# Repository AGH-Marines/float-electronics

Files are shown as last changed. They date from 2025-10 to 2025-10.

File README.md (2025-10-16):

# AGH MARINES Measurement Float Electronics

This repository contains the electronic designs for the AGH MARINES autonomous measurement float.  
It includes schematics, PCB layouts, and block diagrams for the main control board, power distribution, and receiver modules.

---

## Project Structure

- **`Float_Main_PCB`** – Main PCB of the float, based on STM32F401, including EEPROM storage and NRF24 RF communication.  
- **`Float_Power_PCB`** – Power PCB featuring a 12V to 3.3V DC-DC step-down (buck) converter, stepper motor driver (DRV8825 StepStick), and filtering capacitors.  
- **`Float_Receiver_PCB`** – Receiver PCB, receiving data via NRF24 RF module and transmitting it to a PC via USB serial.

---

## Tools & Software

- **Altium Designer** – PCB and schematic design software

---

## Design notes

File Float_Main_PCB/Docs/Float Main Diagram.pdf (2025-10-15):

12 V Battery
Pack (8×AA) | Fuse 0.75 A

Step-Down LM2596
12V -> 3.3V

DRV8825
Stepper Driver

17HD40005
NEMA17 Stepper

STM32F401

M93C66
EEPROM

nRF24L01+
Transceiver

Bar30
Pressure Sensor

Vertical Float

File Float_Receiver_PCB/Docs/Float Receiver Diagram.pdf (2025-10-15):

USB-C
USB 2.0

USBLC6-2SC6
ESD Protection

XC6206
Voltage regulator | STM32F401CCU6

nRF24L01+
Transceiver

Vertical Float Receiver

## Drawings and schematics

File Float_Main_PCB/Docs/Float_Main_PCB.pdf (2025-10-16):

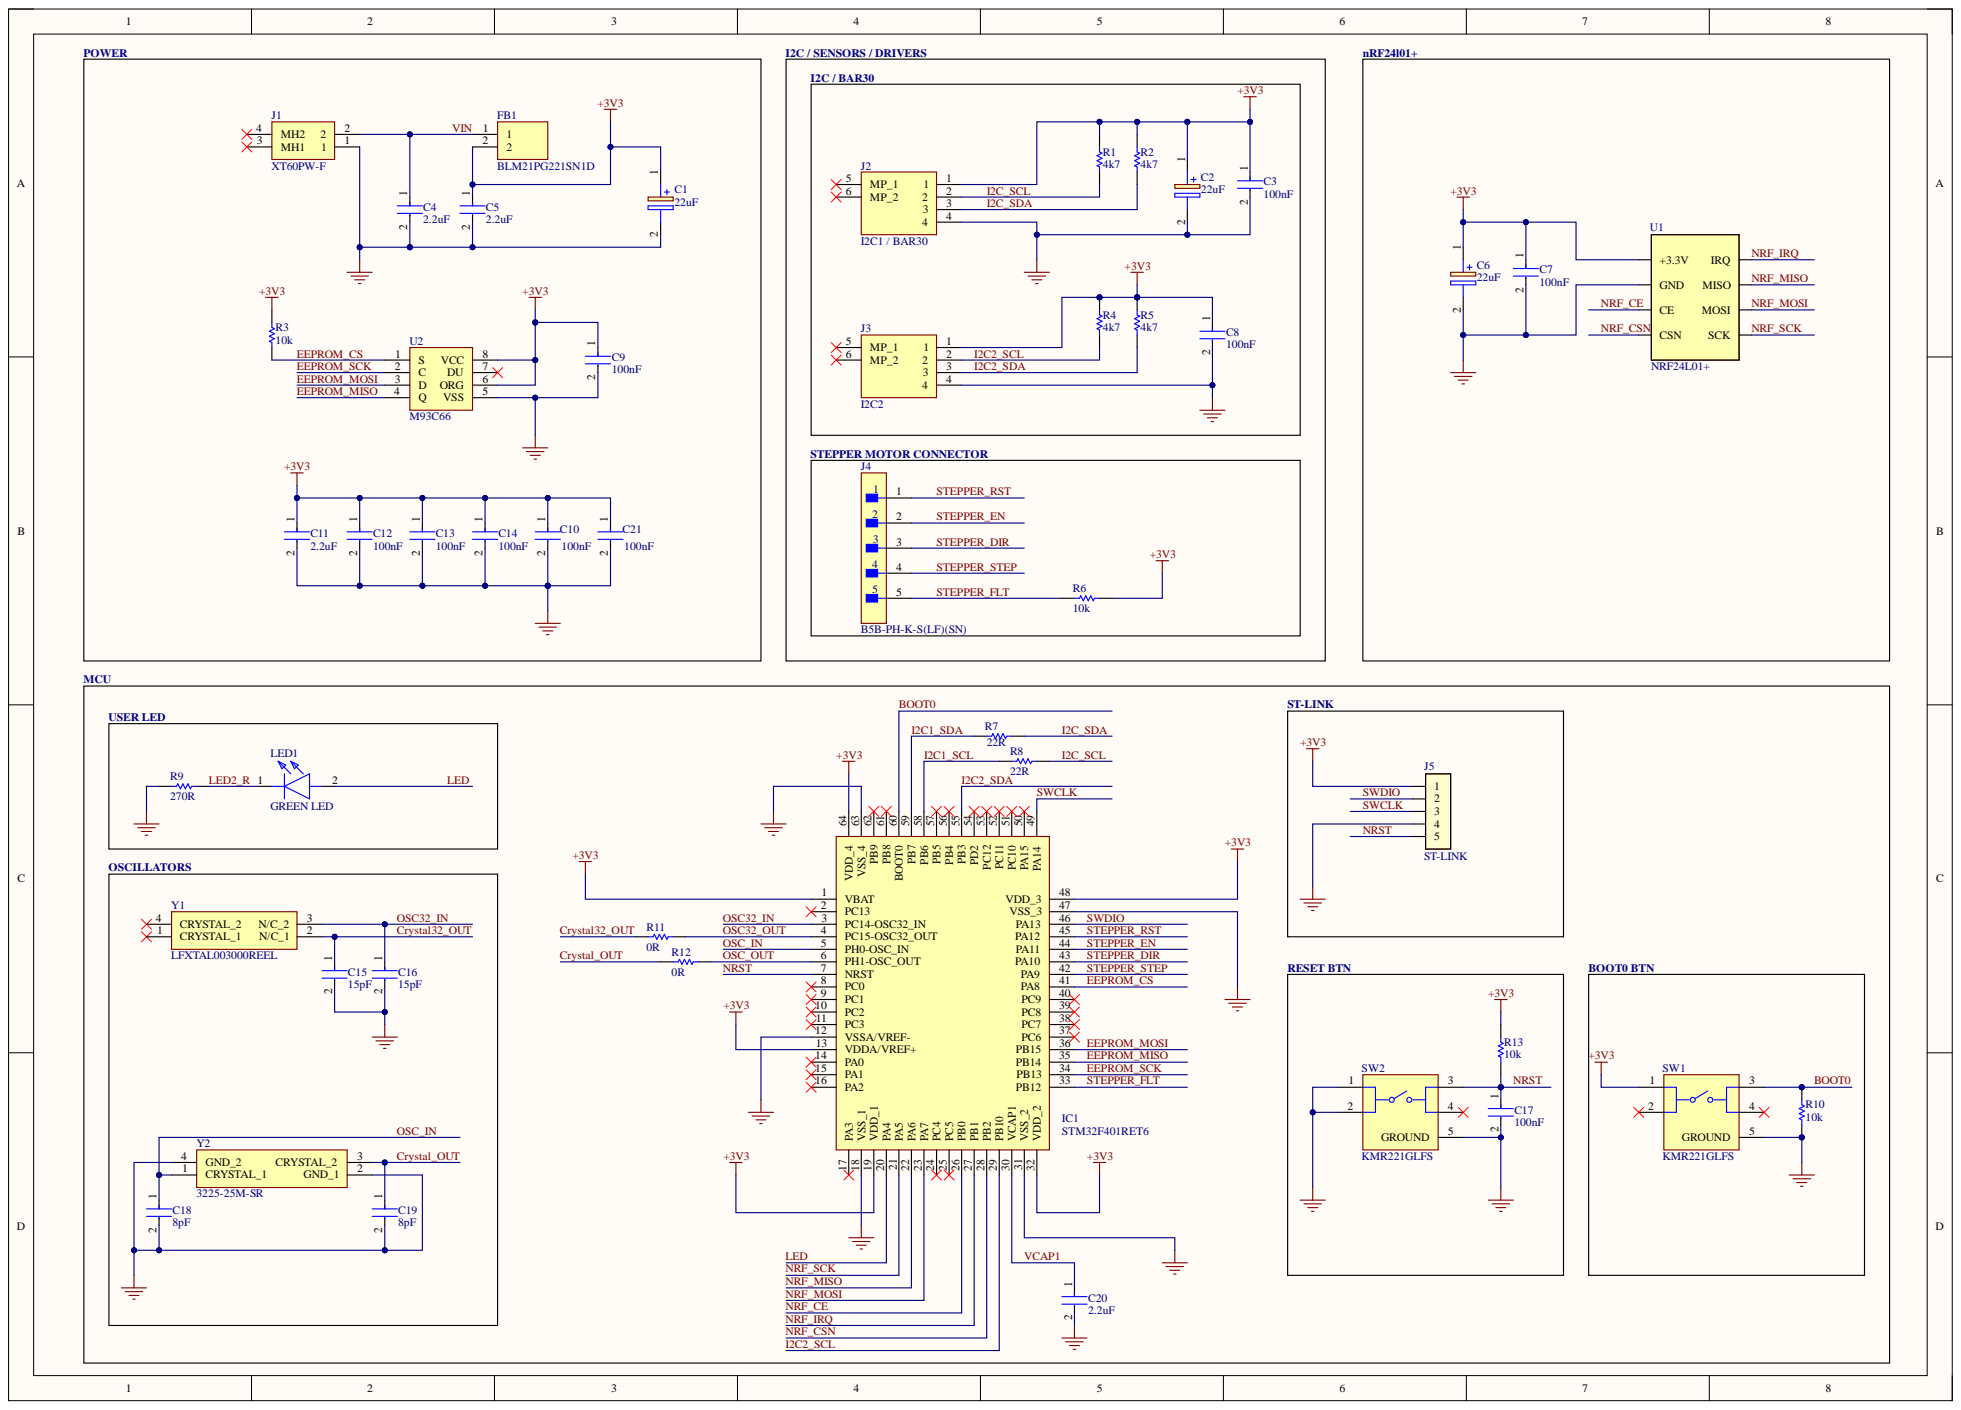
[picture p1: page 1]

I2C1_SCL | R8 I2C_SCL

I2C2_SDA

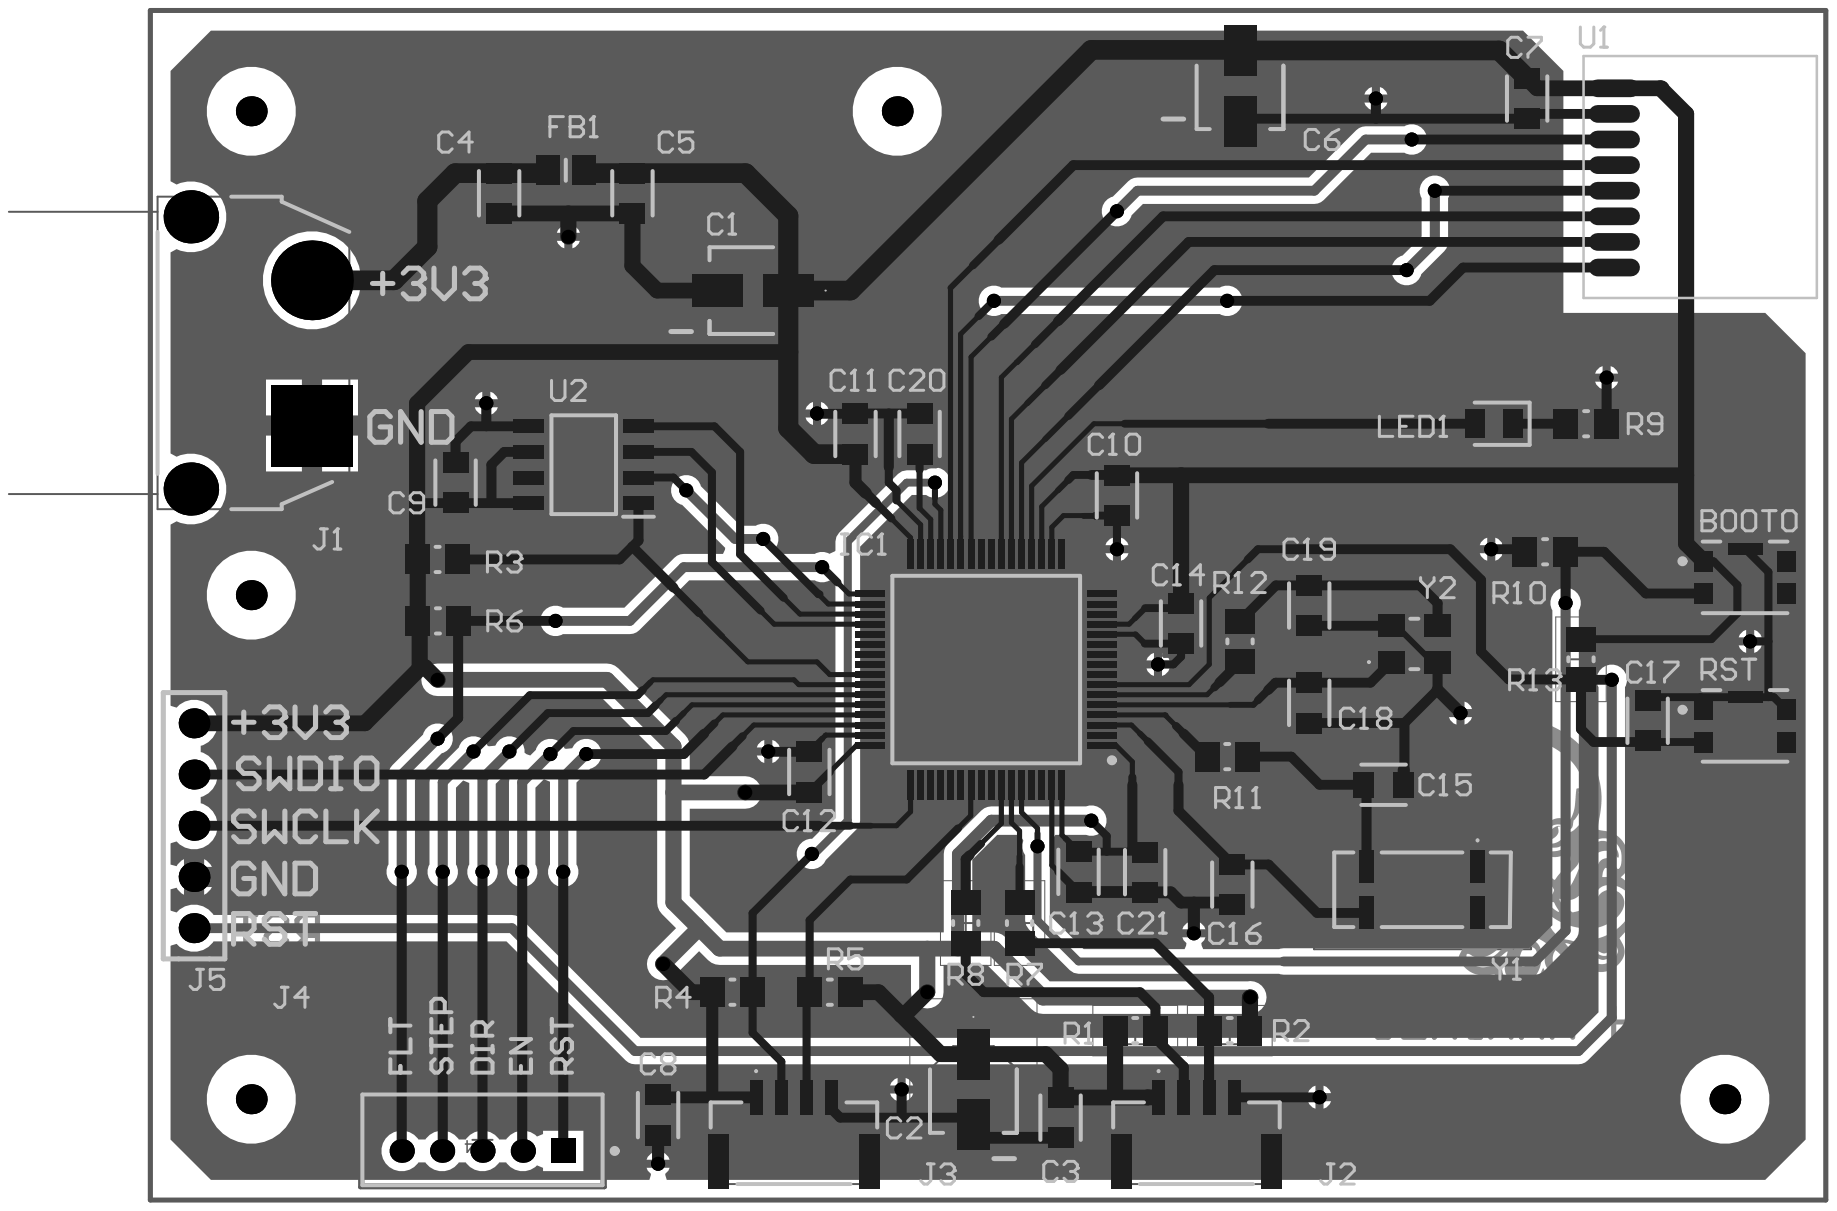
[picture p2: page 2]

Comment | Description | Designator | Footprint | LibRef | Quantity
22uF | Capacitor Polarised | C1, C2, C6 | EEE1AA220WR | EEE1CA100SR | 3
100nF | | C3, C7, C8, C9, C10, C12, C13, C14, C17, C21 | FP-0805-L_2_01_0_2-W_1_25-MFG | CMP-1036-04738-3 | 10
2.2uF | | C4, C5, C11, C20 | FP-0805-L_2_01_0_2-W_1_25-MFG | CMP-1036-04738-3 | 4
15pF | | C15, C16 | FP-0805-L_2_01_0_2-W_1_25-MFG | CMP-1036-04738-3 | 2
8pF | | C18, C19 | FP-0805-L_2_01_0_2-W_1_25-MFG | CMP-1036-04738-3 | 2
BLM21PG221SN1D | FerriteBead | FB1 | BEADC2012X105N | BLM21PG221SN1D | 1
STM32F401RET6 | IntegratedCircuit | IC1 | QFP50P1200X1200X1 60-64N | STM32F401RET6 | 1
XT60PW-F | Connector | J1 | XT60PWF | XT60PW-F | 1
I2C1/ BAR30 | Connector | J2 | SM04BGHSTBLFSN | SM04B-GHS-TB__LF__SN_ | 1
I2C2 | Connector | J3 | SM04BGHSTBLFSN | SM04B-GHS-TB__LF__SN_ | 1
B5B-PH-K-S(LF)(SN) | CONNHEADERVERT 5POS2MM | J4 | FP-B5B-PH-K-S_LF_SN-MFG | CMP-2000-05908-2 | 1
ST-LINK | | J5 | goldpin5 | CMP-008-000005-1 | 1
GREENLED | LED | LED1 | LEDC2012X80N | HSMG-C170 | 1
4k7 | | R1, R2, R4, R5 | RESC2013X60X35ML1 0T20 | CMP-2100-03671-1 | 4
10k | | R3, R6, R10, R13 | RESC2013X60X35ML1 0T20 | CMP-2100-03671-1 | 4
22R | | R7, R8 | RESC2013X60X35ML1 0T20 | CMP-2100-03671-1 | 2
270R | | R9 | RESC2013X60X35ML1 0T20 | CMP-2100-03671-1 | 1
0R | | R11, R12 | RESC2013X60X35ML1 0T20 | CMP-2100-03671-1 | 2
KMR221GLFS | SWITCHTACTILESPST-NO0.05A32V | SW1, SW2 | FP-KMR221GLFS-MFGCMP-10040-000018-1 | | 2
NRF24L01+SMD | | U1 | PCBComponent_1 | NRF24L01+SMD | 1
M93C66 | IntegratedCircuit | U2 | SOIC127P600X175-8NM93C66-WMN6TP | | 1
LFXTAL003000REEL | Crystal or Oscillator | Y1 | LFXTAL003000REEL | LFXTAL003000REEL | 1
3225-25M-SR | Crystal or Oscillator | Y2 | 322525MSR | 3225-25M-SR | 1

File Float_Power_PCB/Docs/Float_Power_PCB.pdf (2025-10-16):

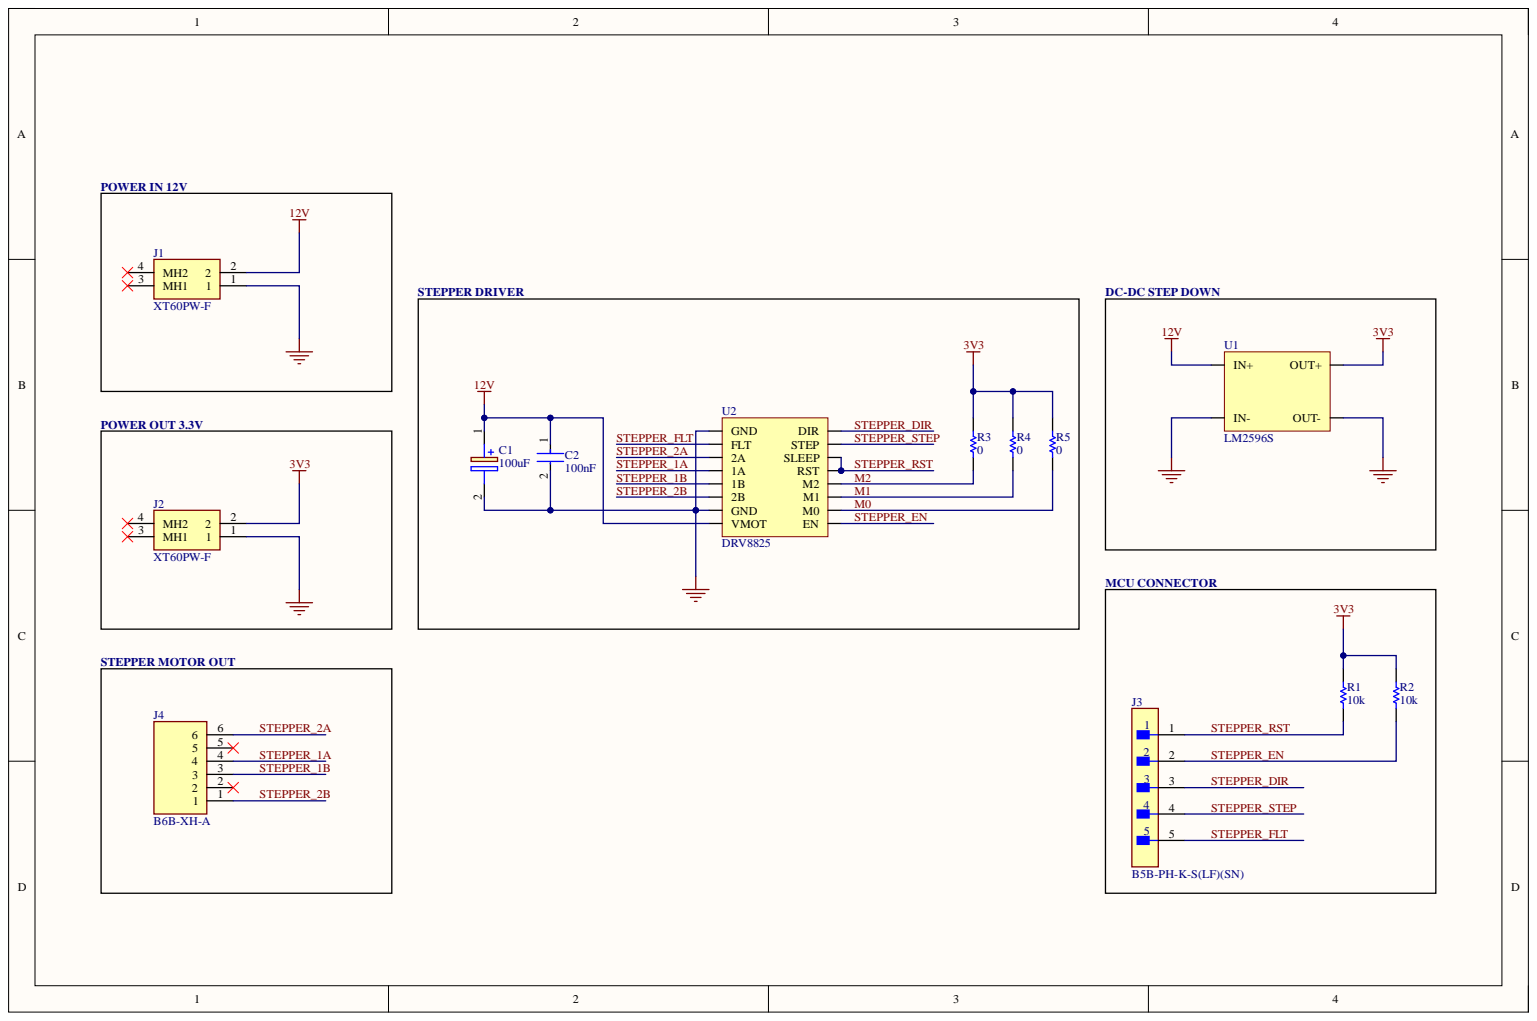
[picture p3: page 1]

DC-DC STEP DOWN

STEPPER_RST
M2

2 | 2 | STEPPER_EN

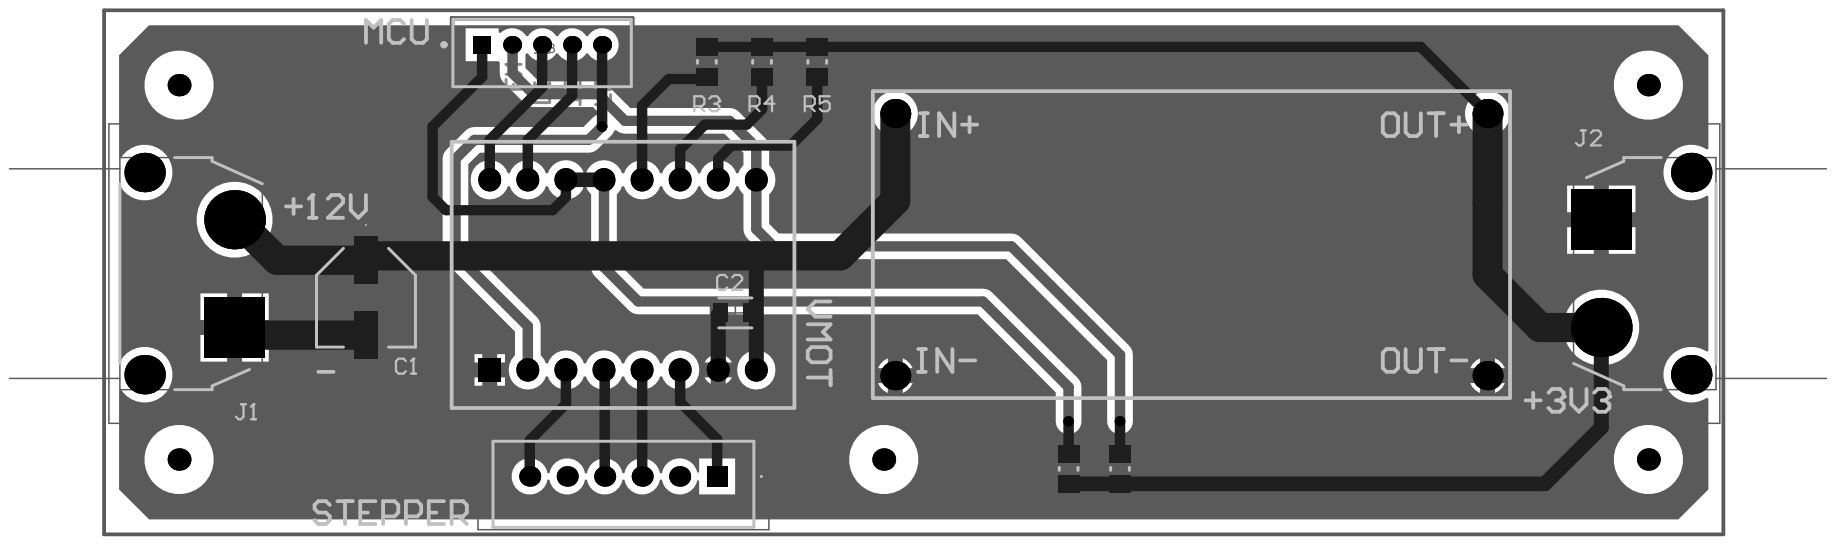
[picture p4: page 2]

Comment | Description | Designator | Footprint | LibRef | Quantity
100uF | Capacitor Polarised | C1 | EEHZA1E101XP | EEHZA1E101XP | 1
100nF | | C2 | FP-0805-L_2_01_0_2-W_1_25-MFG | CMP-1036-04738-3 | 1
XT60PW-F | Connector | J1, J2 | XT60PWF | XT60PW-F | 2
B5B-PH-K-S(LF)(SN) | CONNHEADERVERT 5POS2MM | J3 | FP-B5B-PH-K-S_LF_SN-MFG | CMP-2000-05908-2 | 1
B6B-XH-A | Connector | J4 | B6BXHA | B6B-XH-A | 1
10k | | R1, R2 | RESC2013X60X35ML1 0T20 | CMP-2100-03671-1 | 2
0 | | R3, R4, R5 | RESC2013X60X35ML1 0T20 | CMP-2100-03671-1 | 3
LM2596S | LM2596SDC-DCBuck Converter: step-down voltageregulator, 3A max, 1.23–37Voutput | U1 | LM2596S | LM2596S | 1
DRV8825 | DRV8825stepper motor driver module | U2 | DRV8825 | DRV8825 | 1

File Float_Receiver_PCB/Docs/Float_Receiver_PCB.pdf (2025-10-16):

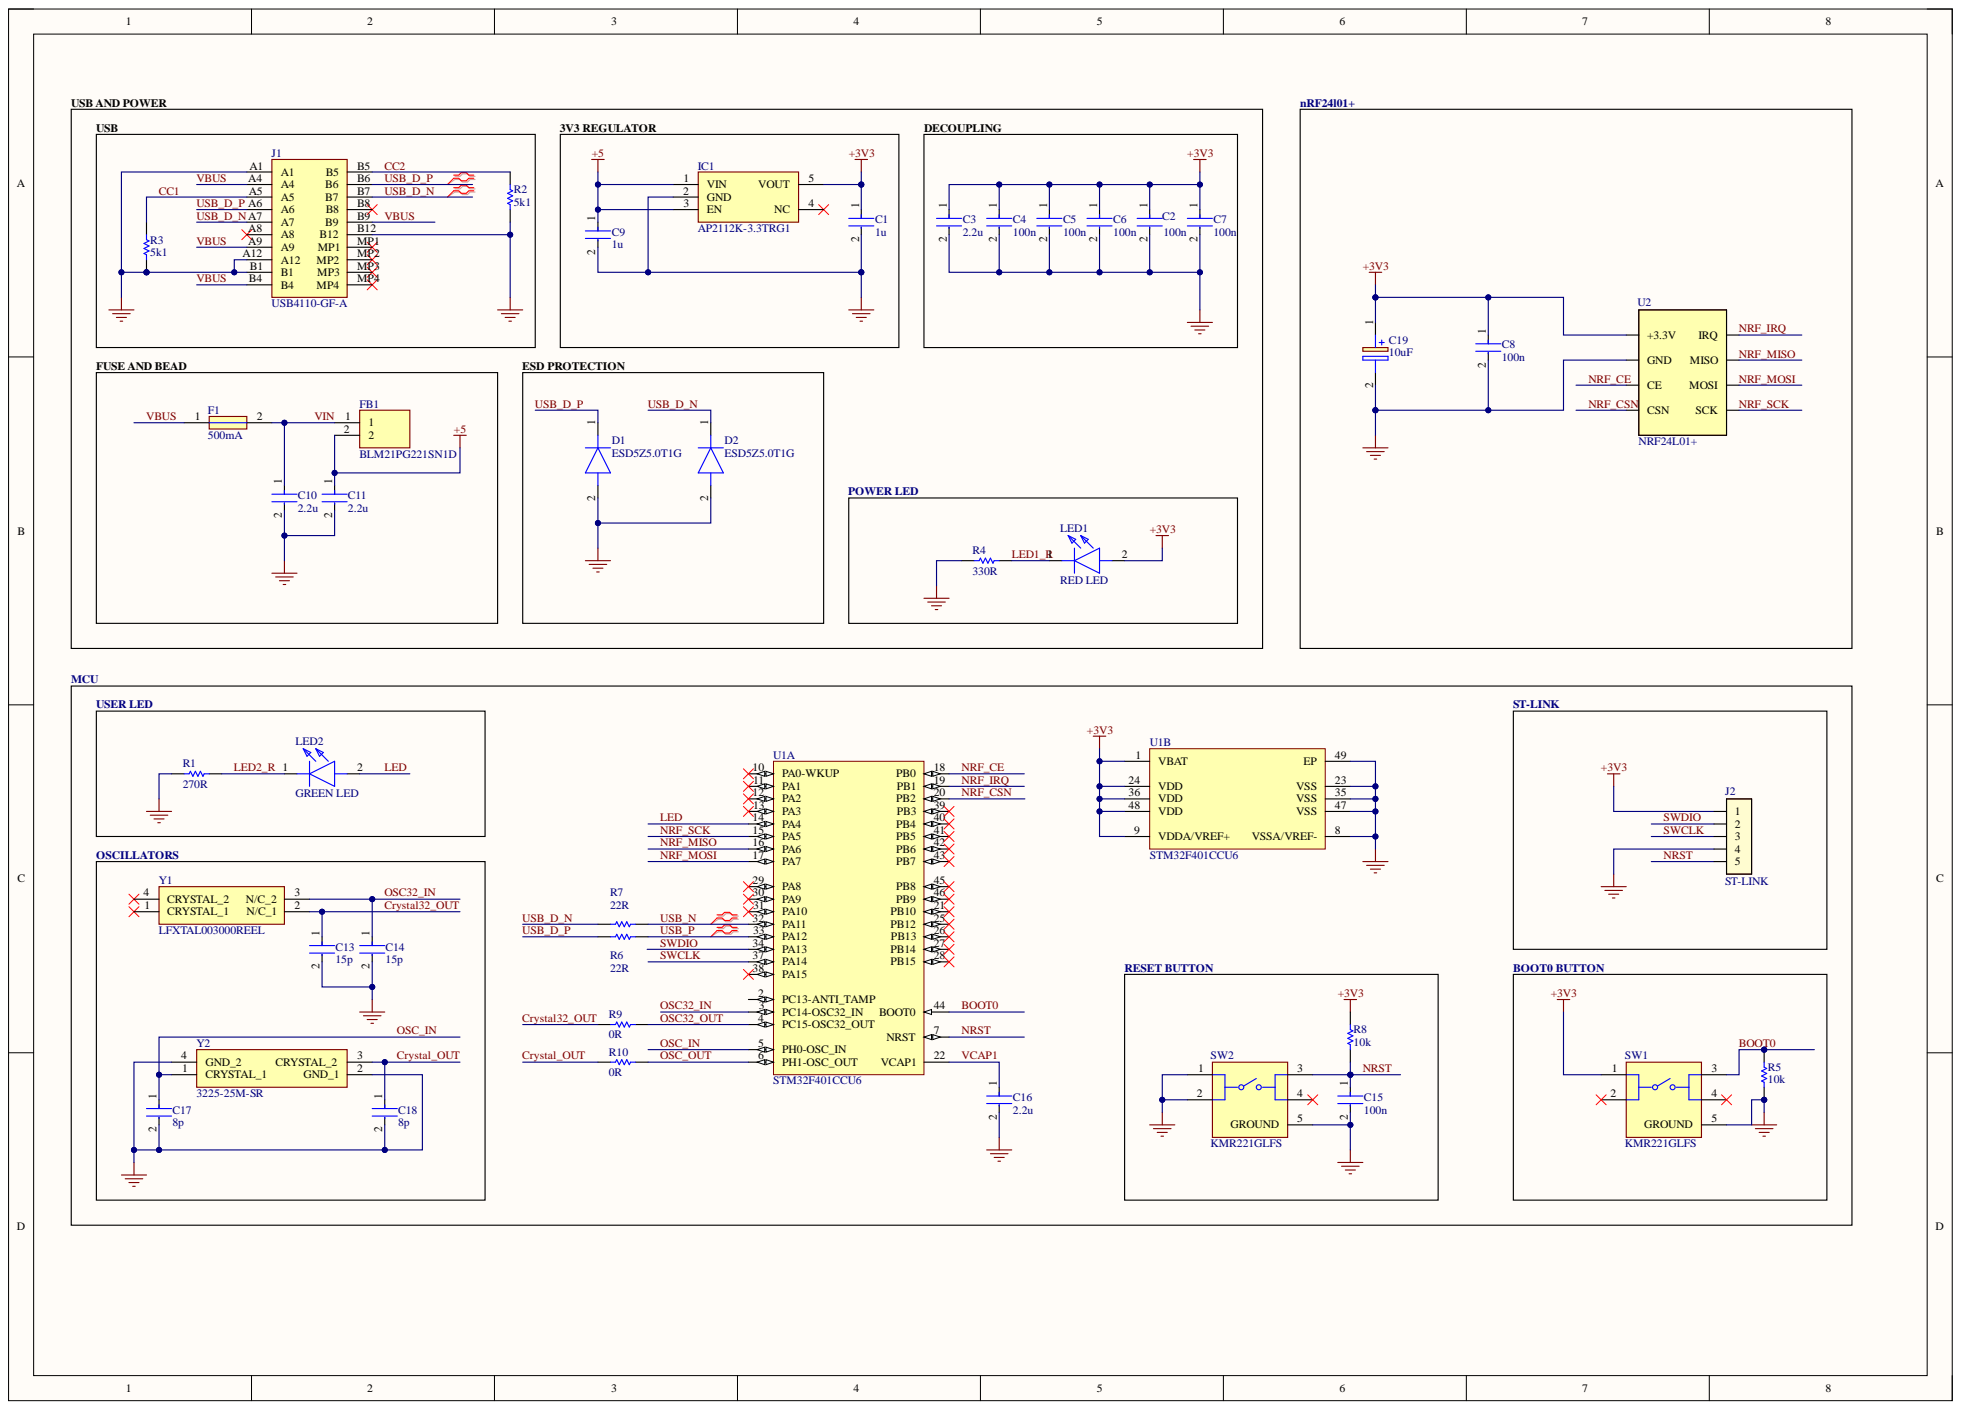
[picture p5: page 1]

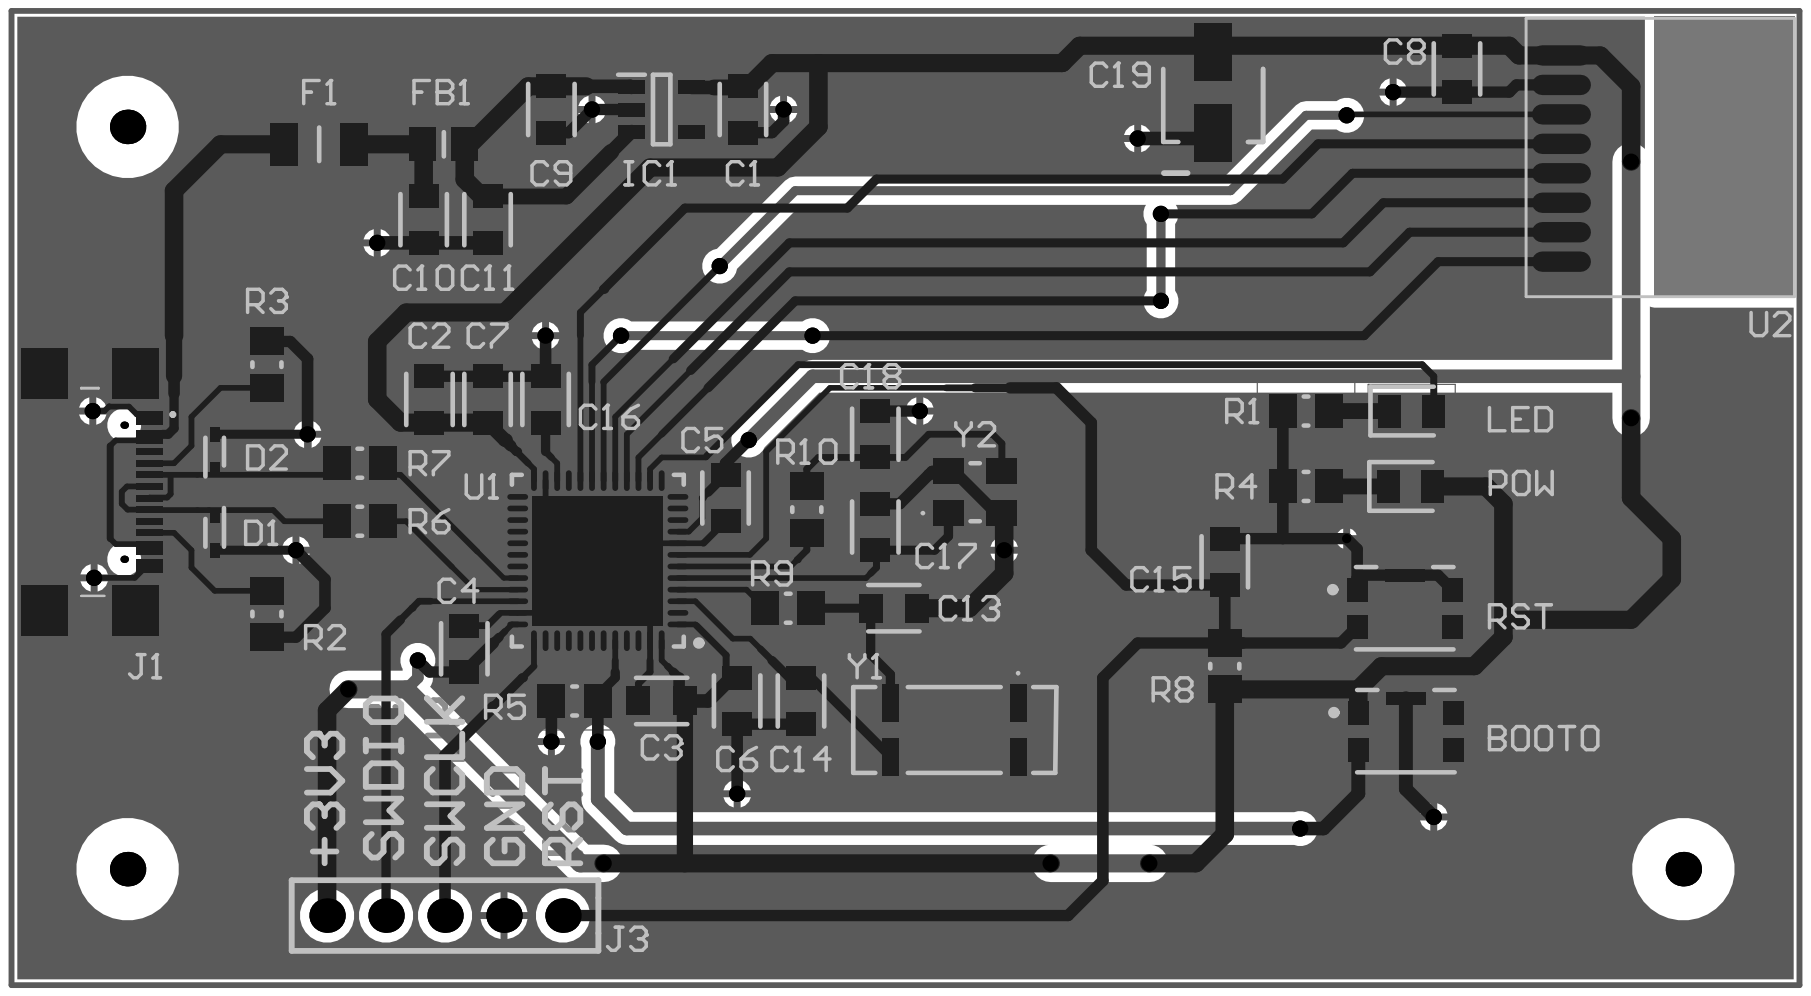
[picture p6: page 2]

Comment | Description | Designator | Footprint | LibRef | Quantity
1u | | C1, C9 | FP-0805-L_2_01_0_2-W_1_25-MFG | CMP-1036-04738-3 | 2
100n | | C2, C4, C5, C6, C7, C8, C15 | FP-0805-L_2_01_0_2-W_1_25-MFG | CMP-1036-04738-3 | 7
2.2u | | C3, C10, C11, C16 | FP-0805-L_2_01_0_2-W_1_25-MFG | CMP-1036-04738-3 | 4
15p | | C13, C14 | FP-0805-L_2_01_0_2-W_1_25-MFG | CMP-1036-04738-3 | 2
8p | | C17, C18 | FP-0805-L_2_01_0_2-W_1_25-MFG | CMP-1036-04738-3 | 2
10uF | Capacitor Polarised | C19 | EEE1AA220WR | EEE1CA100SR | 1
ESD5Z5.0T1G | Diode | D1, D2 | SODFL1608X70N | ESD5Z5.0T1G | 2
500mA | Fuse | F1 | FUSC3216X75N | 0ZCJ0025FF2E | 1
BLM21PG221SN1D | FerriteBead | FB1 | BEADC2012X105N | BLM21PG221SN1D | 1
AP2112K-3.3TRG1 | IntegratedCircuit | IC1 | SOT95P285X140-5N | AP2112K-3.3TRG1 | 1
USB4110-GF-A | Connector | J1 | USB4110GFA | USB4110-GF-A | 1
ST-LINK | | J2 | goldpin5 | goldpin_5 | 1
REDLED | LED | LED1 | LEDC2012X80N | HSMG-C170 | 1
GREENLED | LED | LED2 | LEDC2012X80N | HSMG-C170 | 1
270R | | R1 | RESC2013X60X35ML1 0T20 | CMP-2100-03671-1 | 1
5k1 | | R2, R3 | RESC2013X60X35ML1 0T20 | CMP-2100-03671-1 | 2
330R | | R4 | RESC2013X60X35ML1 0T20 | CMP-2100-03671-1 | 1
10k | | R5, R8 | RESC2013X60X35ML1 0T20 | CMP-2100-03671-1 | 2
22R | | R6, R7 | RESC2013X60X35ML1 0T20 | CMP-2100-03671-1 | 2
0R | | R9, R10 | RESC2013X60X35ML1 0T20 | CMP-2100-03671-1 | 2
KMR221GLFS | SWITCHTACTILESPST-NO0.05A32V | SW1, SW2 | FP-KMR221GLFS-MFGCMP-10040-000018-1 | | 2
STM32F401CCU6 | ARMCortex-M432-bit MCU+FPU, 105 DMIPS, 256kBFlash, 64kBInternal RAM, 36 I/Os, 48-pin UFQFPN, -40to85degC, Tray | U1 | STM-UFQFPN48_N | CMP-0243-00119-2 | 1
NRF24L01+SMD | | U2 | PCBComponent_1 | NRF24L01+SMD | 1
LFXTAL003000REEL | Crystal or Oscillator | Y1 | LFXTAL003000REEL | LFXTAL003000REEL | 1
3225-25M-SR | Crystal or Oscillator | Y2 | 322525MSR | 3225-25M-SR | 1

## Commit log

2025-10-15 Add Float Receiver PCB diagram PDF #1
    Added the Float Receiver Diagram.pdf to the Docs directory.
2025-10-15 Add Float Main PCB diagram PDF #2
    Added the Float Main Diagram.pdf to the Docs directory for reference and documentation of the PCB design.
2025-10-15 Add Float Receiver PCB project files #3
    Added Altium project files for the Float Receiver PCB, including schematics, PCB layout, libraries, and documentation. Also included a .gitignore to exclude temporary and backup files.
    [Float_Receiver_PCB.PcbDoc, Float_Receiver_PCB.SchDoc]
2025-10-16 Update PCB design #3
    Adjusted courtyard for Mechanical Layer 15 – Revised Float Receiver PCB layout and updated the corresponding PDF documentation to reflect the latest design changes.
    [Float_Receiver_PCB.PcbDoc, Float_Receiver_PCB.PrjPcb, Float_Receiver_PCB.SchDoc]
2025-10-16 Add initial Float_Main_PCB project files #5
    Added Altium Designer project file, PCB and schematic documents, and component libraries for the Float_Main_PCB project.
    [Float_Main_PCB.PcbDoc, Float_Main_PCB.PrjPcb, Float_Main_PCB.SchDoc]
2025-10-16 Add Float Receiver PCB fabrication output files #4
    This commit adds generated output files for the Float_Receiver_PCB project, including Gerber layers, drill reports, and status documentation.
    [Float_Receiver_PCB.GBL, Float_Receiver_PCB.GBO, Float_Receiver_PCB.GBP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]
2025-10-16 Add PCB fabrication output files #6
    Added generated fabrication output files (Gerber, drill, reports, etc.) for Float_Main_PCB and updated Float_Main_PCB.PrjPcb to include new output documents and adjust output group configuration.
    [Float_Main_PCB.GBL, Float_Main_PCB.GBO, Float_Main_PCB.GBP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]
2025-10-16 Add Float Power PCB project files #7
    Added Altium Designer project file, schematic, PCB layout, and custom component libraries for the Float Power PCB project.
    [Float_Power_PCB.PcbDoc, Float_Power_PCB.PrjPcb, Float_Power_PCB.SchDoc]
2025-10-16 Add Float Main PCB schematic PDF
    Added the Float_Main_PCB.pdf file containing the schematic documentation for the Float Main PCB.
2025-10-16 Add Float Power PCB project outputs #8
    Added generated output files for Float_Power_PCB including drill reports, Gerber files, and other manufacturing assets.
    [Float_Power_PCB.GBL, Float_Power_PCB.GBO, Float_Power_PCB.GBP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]
